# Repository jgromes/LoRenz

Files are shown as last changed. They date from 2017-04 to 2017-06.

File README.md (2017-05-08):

# LoRenz

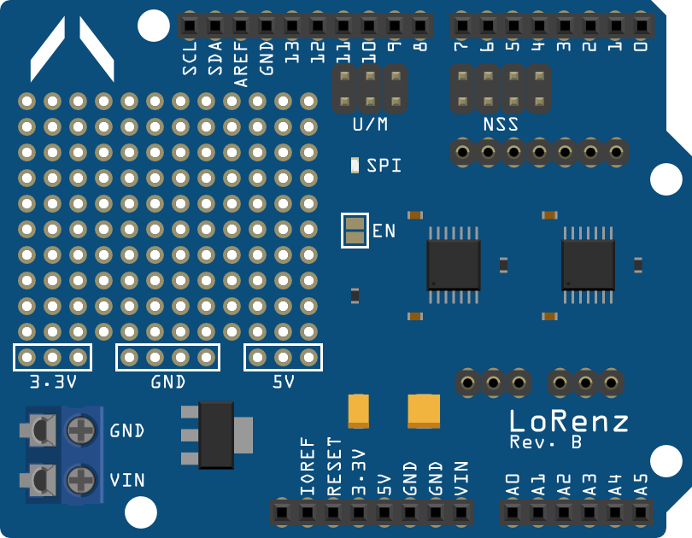
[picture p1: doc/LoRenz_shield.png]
LoRenz shield


## Arduino shield/module to allow easy use of the LoRa communication modules

---

## Work in progress warning
This shield is still early in developement. The shield, module or breakout layouts might be changed at any moment! Watch this repo for progress updates. To get notifications about every commit, use the following link to set up an RSS feed reader: https://github.com/jgromes/LoRenz/commits/master.atom.

---

### This is not the library you are looking for!
If you're looking for Arduino library to use with these modules, it has its own repository: [https://github.com/jgromes/LoRaLib](https://github.com/jgromes/LoRaLib)

---

DISCLAIMER: All schematic and board files are provided 'AS IS'. see `license.txt` for details.

The following is a listing of all the files in the `eagle` folder:

* `shield`

  This will most likely be the starting point of your experiments with LoRa. The shield is compatible with Arduino R3 pinout and has many ways to make your life easier. The main features include:
  
  * Dedicated 3.3V linear regulator to provide more than enough power for the LoRa module.
  * Arduino UNO and Mega compatibility.
  * On-board prototyping area with separate power rails.
  * Coaxial connector on the breakout board for connecting antenna.
  * NSS jumper to allow for LoRenz shield stacking.
  * The shield has a place for LED that will light up when there are data being transferred to/from the LoRa module. To enable this feature, short the EN pads with solder.
  
  Please note that to use this shield, you will need to have a breakout board to mount the LoRa module.
  IMPORTANT: There are several incompatible types of these modules being sold, make sure that your module matches your breakout board!
  
  <b>Arduino UNO setup:</b>
  
  To use LoRenz shield with Arduino UNO, short all the jumpers on U/M pin header (bright red in the picture below). You will also have to short one of the pin pairs on NSS pin header. The NSS pin header allows you to stack up to four LoRenz shields on one Arduino by shorting different pin pair on each shield. If you will only be using one LoRenz shield, I suggest using the pin 7, since that is the default library setting. If you want to stack multiple LoRenz shields, each of them must have a different pin pair shorted. In that case, you will also have to provide the selected pin numbers to LoRaLib. See the library reference for details.
  
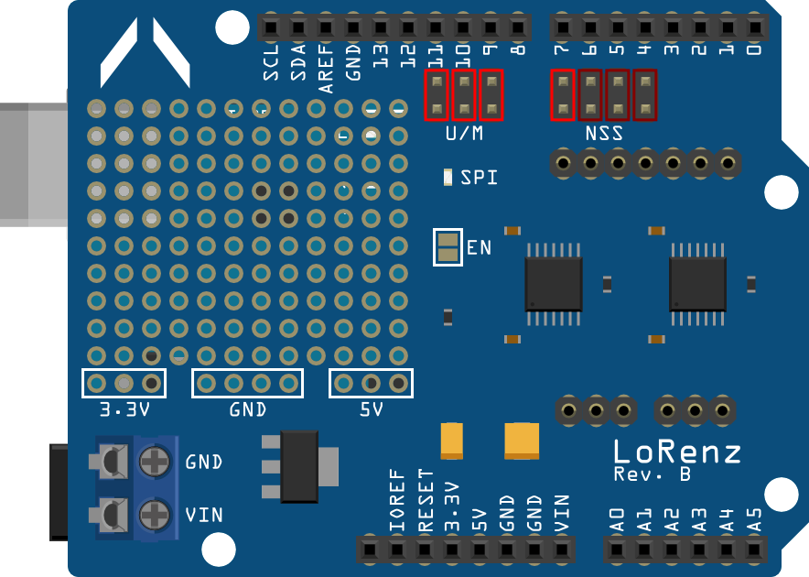
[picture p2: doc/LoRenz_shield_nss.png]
LoRenz shield UNO setup
  
  
  <b>Arduino Mega setup:</b>
  
  To use LoRenz shield with Arduino Mega, remove all the shorting jumpers from U/M pin header. Arduino Mega has the SPI located on pins 50-53, connect the shield to these pins as per the following image. The NSS selection is the same as with Arduino UNO.
  
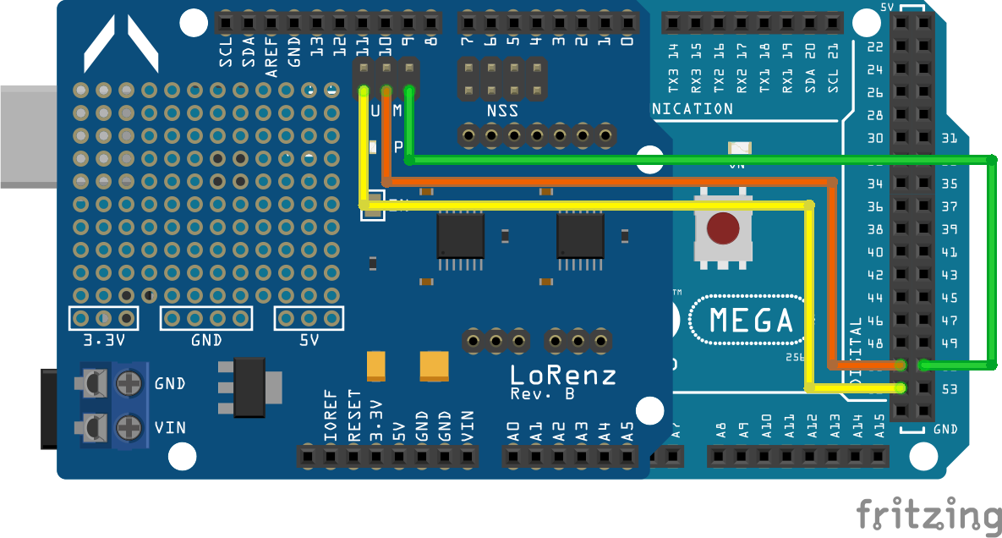
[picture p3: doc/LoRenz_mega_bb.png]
LoRenz shield UNO setup
  

* `breakout_green`

  This breakout board matches the following LoRa module:
  
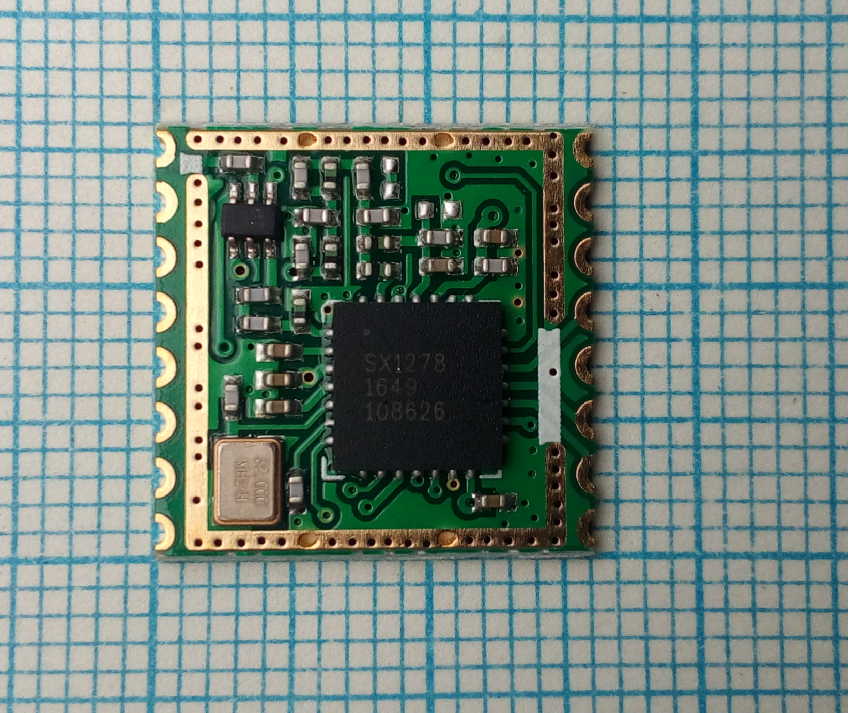
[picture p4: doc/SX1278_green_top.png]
SX1278 Green module top
  
  
  SX1278 Green module bottom
  
  These seem to be fairly common, however, there are several slightly different pinouts. Prior to any soldering, make sure that the module pinout matches the pin description on the breakout board!

* `breakout_blue`

  This breakout board matches the following LoRa module:
  
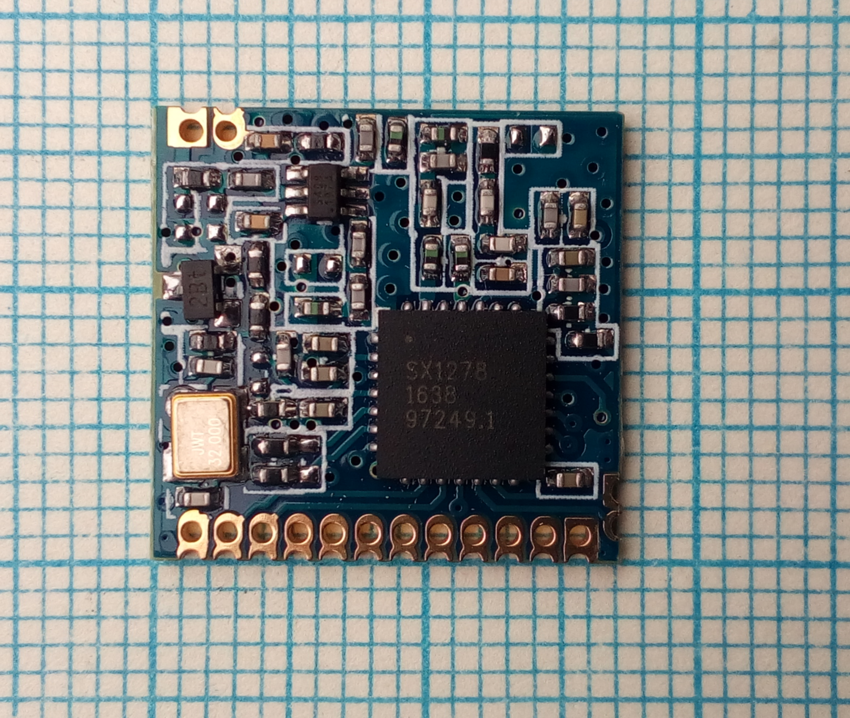
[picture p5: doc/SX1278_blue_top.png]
SX1278 Blue module top
  
  
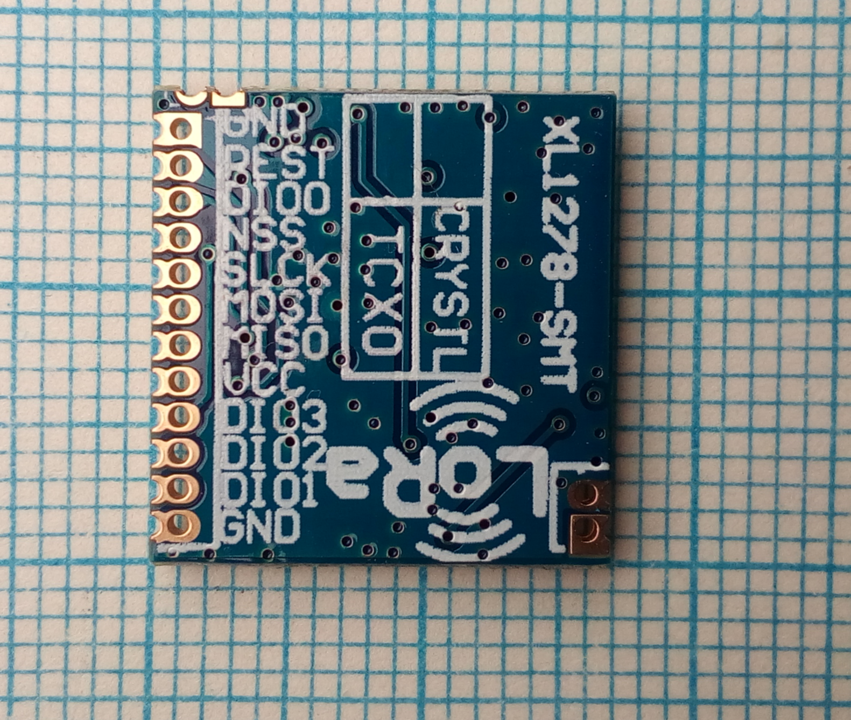
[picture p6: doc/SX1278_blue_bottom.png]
SX1278 Blue module bottom
  
  
  The amount of these modules on the market seems to be declining lately, but it's still possible to buy them. Again, there are multiple different pinouts.

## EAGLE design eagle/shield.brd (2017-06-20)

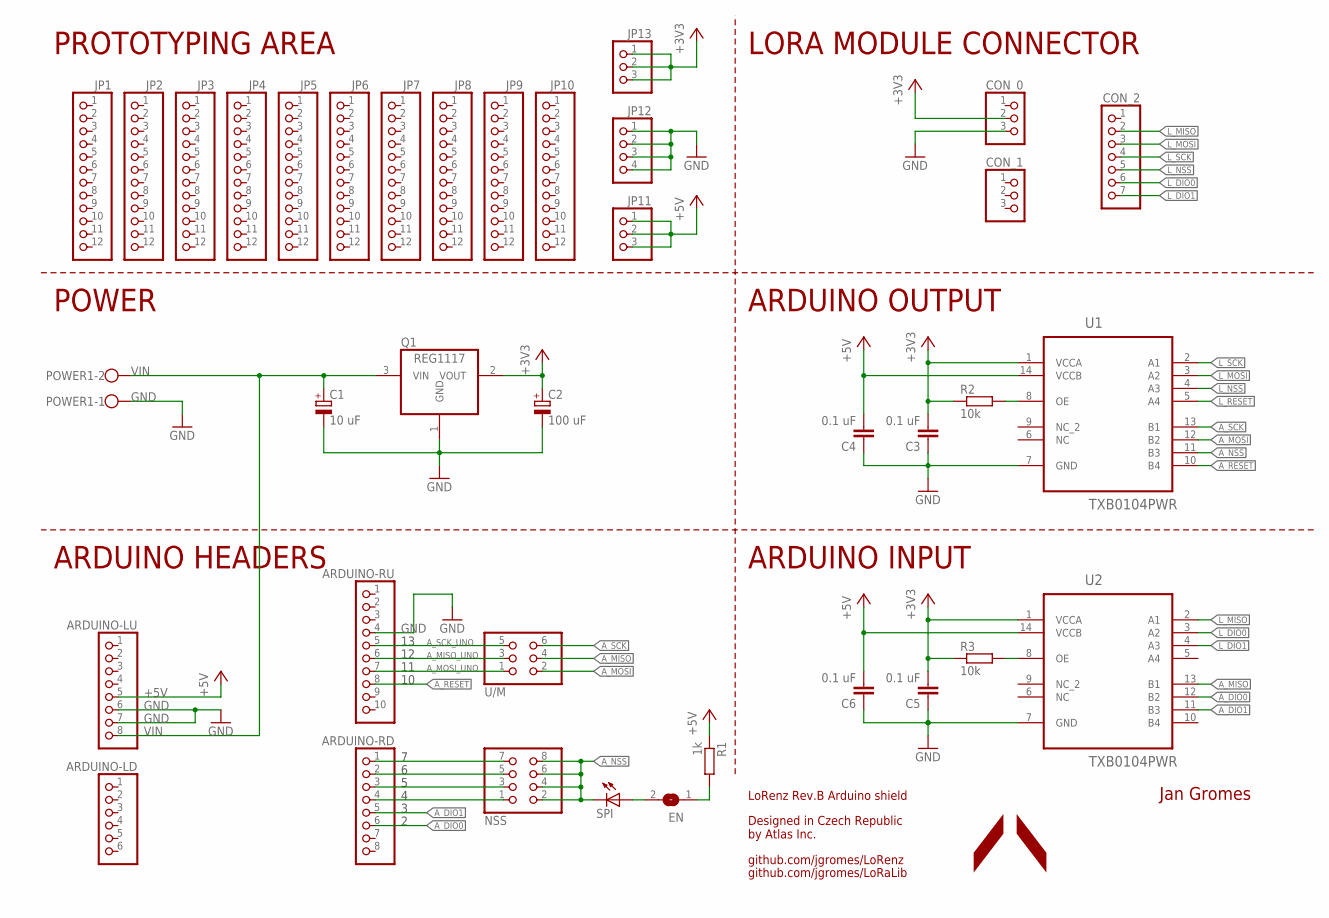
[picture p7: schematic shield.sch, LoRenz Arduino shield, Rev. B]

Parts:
ARDUINO-LD: PINHD-1X6; 1X06
ARDUINO-LU: PINHD-1X8; 1X08
ARDUINO-RD: PINHD-1X8; 1X08
ARDUINO-RU: PINHD-1X10; 1X10
C1: 10 uF; SMC_A
C2: 100 uF; SMC_B
C3, C4, C5, C6: 0.1 uF; C0603
CON_0, CON_1: PINHD-1X3; 1X03
CON_2: PINHD-1X7; 1X07
EN: SJ
JP1, JP2, JP3, JP4, JP5, JP6, JP7, JP8, JP9, JP10: PINHD-1X12-CB; 1X12-CB
JP11, JP13: PINHD-1X3CB; 1X03-CLEANBIG
JP12: PINHD-1X4; 1X04-CLEANBIG
NSS: PINHD-2X4; 2X04
POWER1: W237-102
Q1: REG1117; SOT223
R1: 1k; R0603
R2, R3: 10k; R0603
SPI: LEDSML0603; SML0603
U1, U2: TXB0104PWR; SOP65P640X120-14N
U/M: PINHD-2X3; 2X03

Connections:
+3V3: C2.+, C3.2, C5.2, CON_0.2, JP13.1, JP13.2, JP13.3, Q1.2 (VOUT), R2.1, R3.1, U1.1 (VCCA), U2.1 (VCCA)
+5V: ARDUINO-LU.5, C4.2, C6.2, JP11.1, JP11.2, JP11.3, R1.1, U1.14 (VCCB), U2.14 (VCCB)
A_DIO0: ARDUINO-RD.6, U2.12 (B2)
A_DIO1: ARDUINO-RD.5, U2.11 (B3)
A_MISO: U2.13 (B1), U/M.4
A_MISO_UNO: ARDUINO-RU.6, U/M.3
A_MOSI: U1.12 (B2), U/M.2
A_MOSI_UNO: ARDUINO-RU.7, U/M.1
A_NSS: NSS.2, NSS.4, NSS.6, NSS.8, SPI.C, U1.11 (B3)
A_RESET: ARDUINO-RU.8, U1.10 (B4)
A_SCK: U1.13 (B1), U/M.6
A_SCK_UNO: ARDUINO-RU.5, U/M.5
GND: ARDUINO-LU.6, ARDUINO-LU.7, ARDUINO-RU.4, C1.-, C2.-, C3.1, C4.1, C5.1, C6.1, CON_0.3, JP12.1, JP12.2, JP12.3, JP12.4, POWER1.1, Q1.1 (GND), U1.7 (GND), U2.7 (GND)
L_DIO0: CON_2.6, U2.3 (A2)
L_DIO1: CON_2.7, U2.4 (A3)
L_MISO: CON_2.2, U2.2 (A1)
L_MOSI: CON_2.3, U1.3 (A2)
L_NSS: CON_2.5, U1.4 (A3)
L_RESET: U1.5 (A4)
L_SCK: CON_2.4, U1.2 (A1)
unnamed: ARDUINO-RD.1, NSS.7
unnamed: EN.2, SPI.A
unnamed: ARDUINO-RD.2, NSS.5
unnamed: ARDUINO-RD.3, NSS.3
unnamed: ARDUINO-RD.4, NSS.1
unnamed: EN.1, R1.2
unnamed: R2.2, U1.8 (OE)
unnamed: R3.2, U2.8 (OE)
VIN: ARDUINO-LU.8, C1.+, POWER1.2, Q1.3 (VIN)

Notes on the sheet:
LoRenz Rev.B Arduino shield
Designed in Czech Republic by Atlas Inc.
github.com/jgromes/LoRenz
github.com/jgromes/LoRaLib
Jan Gromes
C:/Users/Honza/Desktop/ATLAS/atlas_logo_notext_gs.bmp
PROTOTYPING AREA
LORA MODULE CONNECTOR
ARDUINO INPUT
POWER
ARDUINO OUTPUT
ARDUINO HEADERS

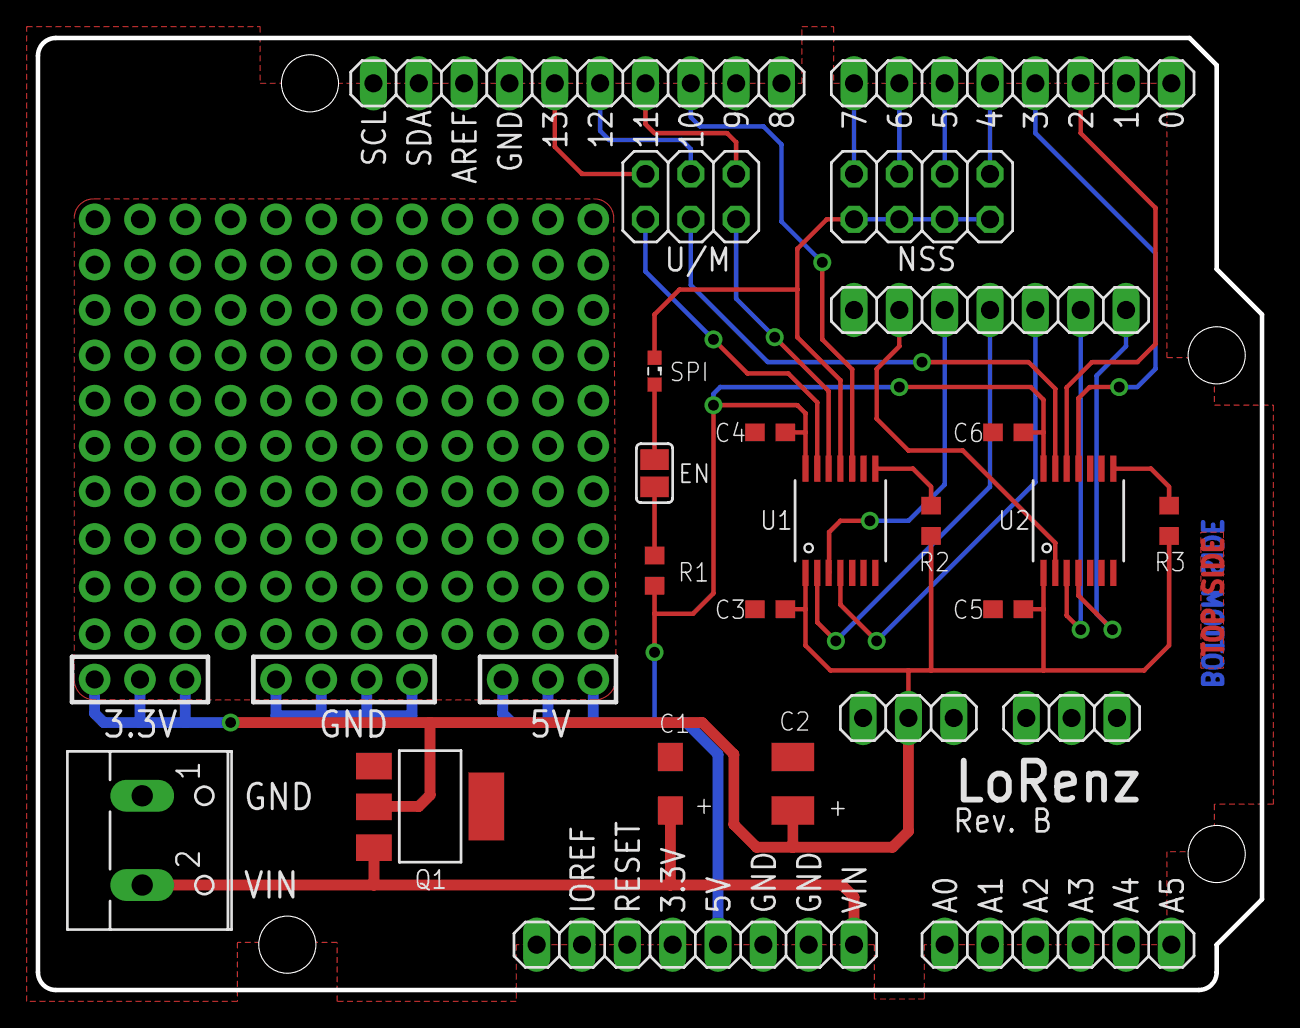
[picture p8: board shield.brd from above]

Board: 2 copper layers, 68.6 x 53.3 mm, 37 parts (0 on the bottom side), 28 nets.

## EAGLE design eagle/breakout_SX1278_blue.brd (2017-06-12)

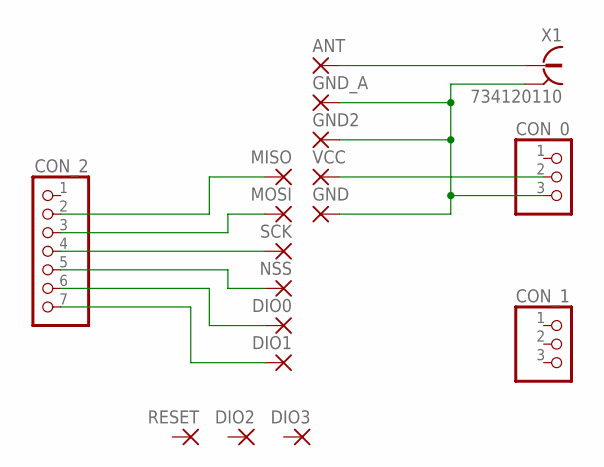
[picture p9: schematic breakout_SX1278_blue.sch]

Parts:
ANT: SMD1; SMD0,65-1,27
CON_0, CON_1: PINHD-1X3; 1X03
CON_2: PINHD-1X7; 1X07
DIO0, DIO1, DIO2, DIO3: SMD1; SMD0,65-1,27
GND, GND2: SMD1; SMD0,65-1,27
GND_A: SMD1; SMD0,65-1,27
MISO: SMD1; SMD0,65-1,27
MOSI: SMD1; SMD0,65-1,27
NSS: SMD1; SMD0,65-1,27
RESET: SMD1; SMD0,65-1,27
SCK: SMD1; SMD0,65-1,27
VCC: SMD1; SMD0,65-1,27
X1: 734120110

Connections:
3.3V: CON_0.2, VCC.1; also elsewhere on the board
ANT: ANT.1, X1.1
DIO0: CON_2.6, DIO0.1
DIO1: CON_2.7, DIO1.1
GND: CON_0.3, GND.1, GND2.1, GND_A.1, X1.S@1 (2), X1.S@2 (2), X1.S@3 (2)
MISO: CON_2.2, MISO.1
MOSI: CON_2.3, MOSI.1
NSS: CON_2.5, NSS.1
SCK: CON_2.4, SCK.1

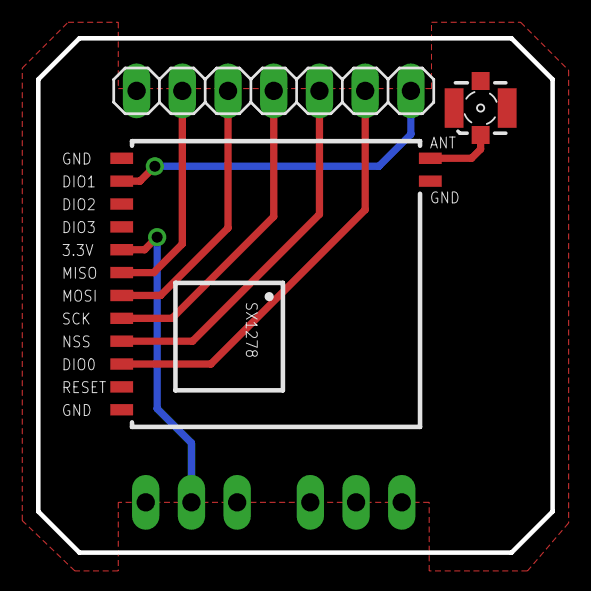
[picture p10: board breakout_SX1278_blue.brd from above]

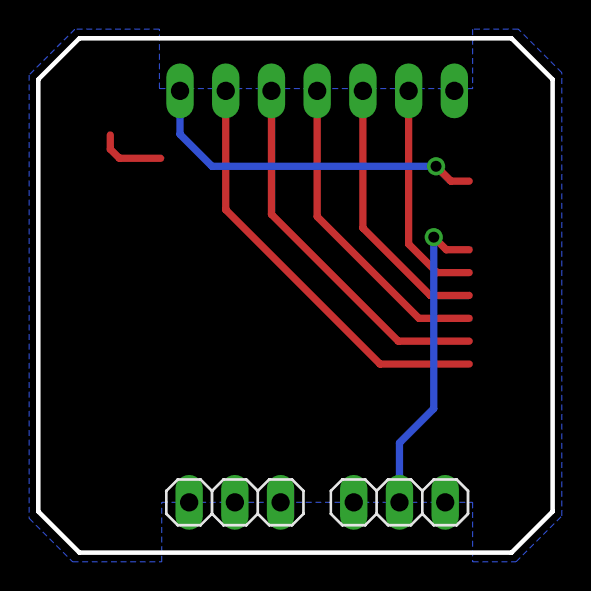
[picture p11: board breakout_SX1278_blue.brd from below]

Board: 2 copper layers, 28.6 x 28.6 mm, 18 parts (2 on the bottom side), 9 nets.

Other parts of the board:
3.3V: SMD0,65-1,27

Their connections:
3.3V: 3.3V.1; also elsewhere on the board

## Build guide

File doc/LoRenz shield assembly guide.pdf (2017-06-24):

# LoRenz rev.B shield assembly guide

Note 1: Components in Tables 1 and 2 are listed in recommended placement order. Note 2: This document was last updated on 15/05/17.

Table 1: Components

Component | Value | Package | Placed
U1 | TXB0104PWR | TSSOP14
U2 | TXB0104PWR | TSSOP14
R2 | 10k | 0603
R3 | 10k | 0603
C6 | 0.1 µF | 0603
C5 | 0.1 µF | 0603
C4 | 0.1 µF | 0603
C3 | 0.1 µF | 0603
SPI | LED | 0603
R1 | 1k | 0603
C1 | 10 µF | A
C2 | 100 µF | B
Q1 | LD1117 | SOT223

Table 2: Pin headers and terminals

Component | Placed
LoRa module pin headers
U/M
NSS
Arduino digital pins (lower) Arduino digital pins (higher) Arduino analog pins
Arduino power pins
Power terminal

This page intentionally left blank

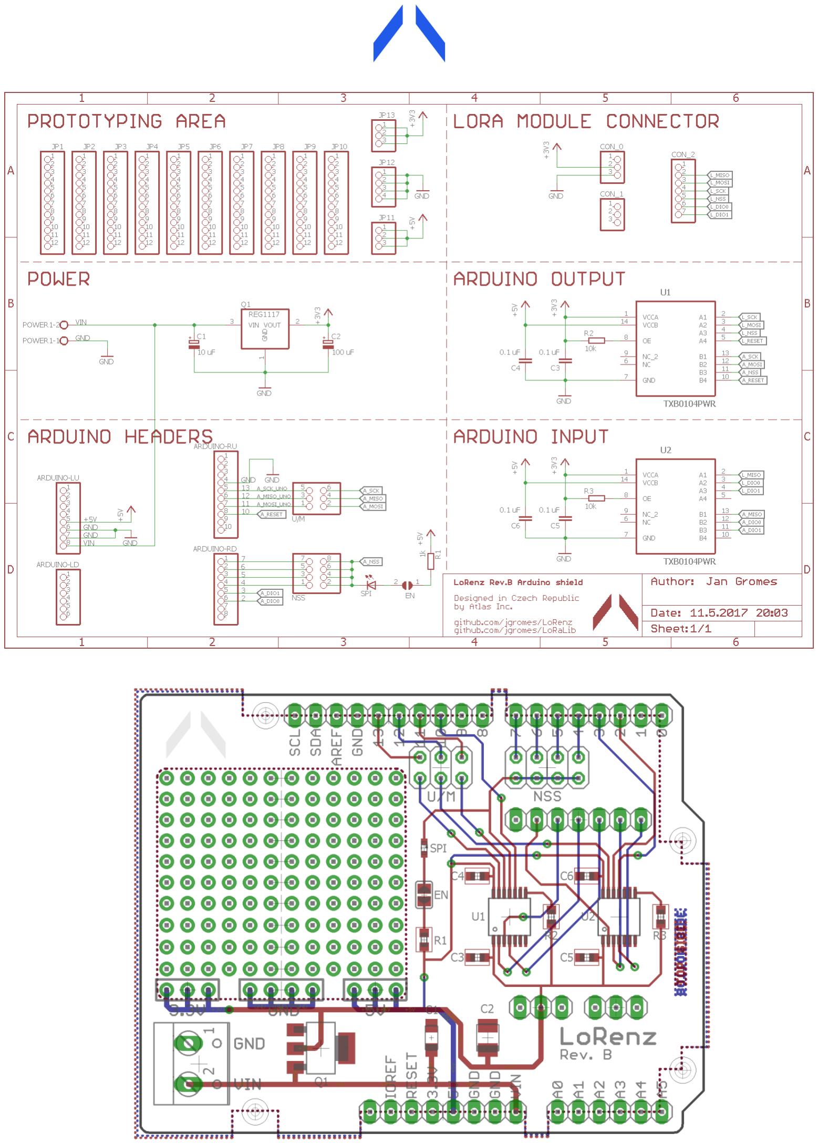
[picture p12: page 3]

This page intentionally left blank

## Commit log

2017-03-17 Added shield and breakout boards Eagle files
    [breakout_blue.brd, breakout_blue.sch, breakout_green.brd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]
2017-03-20 Fixed LoRa module pad spacing
    [breakout_green.brd]
2017-04-01 Shield layout update
    Added two separate TXB0104 instead of one TXB0108 (signal direction issues), added EN solder jumper for LED, removed battery level measurement, increased the protoyping area size, general layout changes for easier soldering.
    [shield.brd, shield.sch]
2017-04-01 Shield and breakout layout update
    Added a gap to the pin headers on LoRa breakout board and the shield to enforce breakout orientation.
    [breakout_blue.brd, breakout_blue.sch, breakout_green.brd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]
2017-04-02 Added SX1278 outline as an orientation marker
    [breakout_SX1278_blue.brd, breakout_SX1278_green.brd]
2017-04-05 Orientation marker fix
    [breakout_SX1278_green.brd]
2017-05-05 Module layout update
    [breakout_SX1278_blue.brd, breakout_SX1278_blue.sch, breakout_SX1278_green.brd]
2017-05-06 Changed package of C2
    [shield.brd, shield.sch]
2017-05-11 Breakout dimensions fix
    [breakout_SX1278_blue.brd, breakout_SX1278_green.brd]
2017-05-11 Major layout update, read details
    The layouts of shield and all breakout boards were changed to match the new multiprotocol standard.
    IMPORTANT: The new shield is NOT compatible with the old breakout boards!
    [breakout_SX1278_blue.brd, breakout_SX1278_blue.sch, breakout_SX1278_green.brd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]
2017-06-12 Fixed power connector orientation
    [breakout_SX1278_blue.brd, breakout_SX1278_green.brd]
2017-06-20 Release 1.0
    [breakout_SX1278_blue.sch, breakout_SX1278_green.sch, shield.brd]
2017-06-21 Updated docs to match current release
2017-06-24 Added shield assembly guide
